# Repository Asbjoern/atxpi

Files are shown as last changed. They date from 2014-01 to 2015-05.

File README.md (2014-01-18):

# atxpi #

Raspberry Pi ATX power controller using the [teensy](http://www.pjrc.com/teensy/) microcontroller. The atxpi emulates ACPI behavior, handling ATX power supply states, power / reset buttons, and LEDs.

---

 - [Parts List](#parts-list)
 - [Power / Reset Buttons](#buttons)
 - [GPIO Pins](#gpio)
 - [RPI Power Scripts Installation](#power-scripts)
	- [Arch](#power-scripts-arch)
	- [Raspbian](#power-scripts-raspbian)
 - [Schematic](#schematic)

---

<h2 id="parts-list">Parts List</h2>

 - [Teensy 2.0](http://www.pjrc.com/store/teensy.html)
 - [Logic Level Converter](https://www.sparkfun.com/products/11978)
 - [ATX Connector Breakout Board](https://www.sparkfun.com/products/9558)
 - [ATX Power Supply Connector](https://www.sparkfun.com/products/9498)

---

<h2 id="buttons">Power / Reset Buttons</h2>

 - Power state 0:
	- Power button pressed: power on
	- Reset button pressed: do nothing

 - Power state 1:
	- Power button pressed for 1 second: Tell RPI to shutdown by setting GPIO pin 23 HIGH
	- Power button pressed for 5 seconds: Force power off
	- Reset button pressed for 1 second: Force power cycle

---

<h2 id="gpio">GPIO Pins</h2>

The RPI will monitor GPIO 23 and shutdown if it is set to HIGH. After the RPI boots it will set GPIO 24 HIGH, telling the teensy that the RPI is up. When GPIO 24 goes from HIGH to LOW the teensy will wait 5 seconds then cut power, unless GPIO 25 is HIGH. GPIO 25 is set to HIGH when the RPI is rebooting, preventing the teensy from cutting power when GPIO 24 changes from HIGH to LOW.

---

<h2 id="power-scripts">RPI Power Scripts Installation</h2>

<h3 id="power-scripts-arch">Arch</h3>

Log into the RPI and become root. You will need to install git and WiringPi:

	[root@alarmpi ~]$ pacman -Sy git wiringpi

Next, clone the repo and copy required files.

	[root@alarmpi ~]$ git clone https://github.com/steelcaverobotics/atxpi.git
	[root@alarmpi ~]$ mkdir /opt/atxpi
	[root@alarmpi ~]$ cp atxpi/rpi_power_scripts/*.sh /opt/atxpi/
	[root@alarmpi ~]$ chmod 755 /opt/atxpi/*.sh
	[root@alarmpi ~]$ cp atxpi/service_files/arch/*.service /usr/lib/systemd/system/

Then enable the services, skipping `atxpi-gpio-shutdown.service` if you don't want the RPI to shutdown when the power button is pressed.

	[root@alarmpi ~]$ systemctl enable atxpi-gpio-boot.service
	[root@alarmpi ~]$ systemctl enable atxpi-gpio-reboot.service
	[root@alarmpi ~]$ systemctl enable atxpi-gpio-shutdown.service

Finally, start the services. Do not start `atxpi-gpio-reboot.service`, as this will be started when the RPI is rebooting.

	[root@alarmpi ~]$ systemctl start atxpi-gpio-boot.service
	[root@alarmpi ~]$ systemctl start atxpi-gpio-shutdown.service

<h3 id="power-scripts-raspbian">Raspbian</h3>

Log into the RPI and become root. You will need to install git and WiringPi:

	root@raspberrypi:~# apt-get install git-core
	root@raspberrypi:~# git clone git://git.drogon.net/wiringPi
	root@raspberrypi:~# cd wiringPi/
	root@raspberrypi:~# ./build

Next, clone the repo and copy required files.

	root@raspberrypi:~# git clone https://github.com/steelcaverobotics/atxpi.git
	root@raspberrypi:~# mkdir /opt/atxpi
	root@raspberrypi:~# cp atxpi/rpi_power_scripts/*.sh /opt/atxpi/
	root@raspberrypi:~# chmod 755 /opt/atxpi/*.sh
	root@raspberrypi:~# cp atxpi/service_files/raspbian/* /etc/init.d/
	root@raspberrypi:~# chmod 755 /etc/init.d/atxpi-gpio-*

Then enable the services, skipping `atxpi-gpio-shutdown` if you don't want the RPI to shutdown when the power button is pressed.

	root@raspberrypi:~# update-rc.d atxpi-gpio-boot defaults
	root@raspberrypi:~# update-rc.d atxpi-gpio-reboot defaults
	root@raspberrypi:~# update-rc.d atxpi-gpio-shutdown defaults

Finally, start the services.

	root@raspberrypi:~# /etc/init.d/atxpi-gpio-boot start
	root@raspberrypi:~# /etc/init.d/atxpi-gpio-shutdown start

---

<h2 id="schematic">Schematic</h2>

<a href="https://dl.dropboxusercontent.com/u/7536257/atxpi/atxpi_schematic_large.png" target="_blank">
	atxpi schematic
</a>

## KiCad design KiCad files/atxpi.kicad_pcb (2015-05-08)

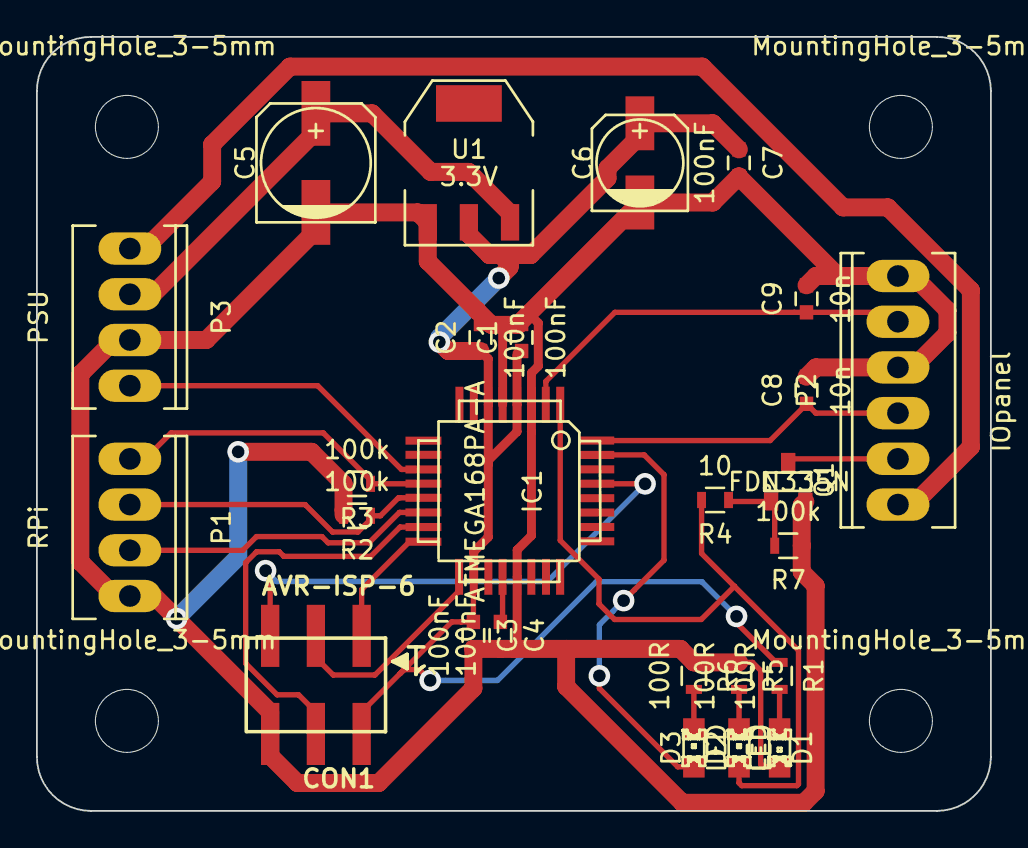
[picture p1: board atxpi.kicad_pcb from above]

Board: 2 copper layers, 53.0 x 43.0 mm, 30 parts (0 on the bottom side), 22 nets.

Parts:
C1, C2, C3, C4, C7: 100nF; C_0603
C5: >100uF; c_elec_6.3x5.8
C6: 10uF; c_elec_5x5.3
C8, C9: 10n; C_0603
CON1: AVR-ISP-6; pin_2x6_smd
D1, D2, D3: LED; LED-0805
IC1: ATMEGA168PA-A; TQFP-32
MountingHole_3-5mm, MountingHole_3-5mm#2, MountingHole_3-5mm#3, MountingHole_3-5mm#4: VAL**; MountingHole_3-5mm
P1: RPi; Socket_MOLEX-KK-RM2-54mm_Lock_4pin_straight
P2: IOpanel; Socket_MOLEX-KK-RM2-54mm_Lock_6pin_straight
P3: PSU; Socket_MOLEX-KK-RM2-54mm_Lock_4pin_straight
Q1: FDN335N; SOT-23
R1, R5, R6: 100R; R_0603
R2, R3, R7: 100k; R_0603
R4: 10; R_0603
U1: 3.3V; SOT-223

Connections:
+3.3V: C1.1, C2.1, C3.1, C6.1, C7.1, CON1.2, IC1.4, IC1.6, IC1.18, R1.1, U1.2
+5V: C5.1, P3.2, U1.3
+12V: P2.1, P3.1
/MISO: CON1.1, IC1.16
/MOSI: CON1.4, IC1.15
/PS_ON: IC1.11, P3.4
/PWR_LED: D2.1, IC1.1, R4.2
/PWR_SW: C8.1, IC1.32, P2.3
/RDY_LED: D3.1, IC1.31
/RPI_REBOOT_25: IC1.12, P1.1, R3.1
/RPI_UP_24: IC1.13, P1.2, R2.1
/RST: CON1.5, IC1.29
/RST_SW: C9.1, IC1.2, P2.5
/SCK: CON1.3, IC1.17
/SHTDWN_23: IC1.14, P1.3
GND: C1.2, C2.2, C3.2, C4.2, C5.2, C6.2, C7.2, C8.2, C9.2, CON1.6, D1.2, IC1.3, IC1.5, IC1.21, P1.4, P2.4, P2.6, P3.3, Q1.2, R2.2, R3.2, R5.1, R6.1, R7.1, U1.1
unnamed: C4.1, IC1.20
unnamed: D1.1, R1.2
unnamed: D2.2, R5.2
unnamed: D3.2, R6.2
unnamed: P2.2, Q1.3
unnamed: Q1.1, R4.1, R7.2

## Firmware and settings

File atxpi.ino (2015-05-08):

#define DEBUG 0

#include <Bounce2.h>
#include <elapsedMillis.h>

#define READY_LED 1
#define POWER_LED 3
#define POWER_SWITCH 2
#define RESET_SWITCH 4
#define PI_GPIO_23 10 // used to tell rpi to shutdown
#define PI_GPIO_24 9 // used to tell teensy the rpi is up, and when to cut power
#define PI_GPIO_25 8 // used to tell the teensy the rpi is rebooting (don't cut power)
#define PS_ON 7


int power_state = 0;
int soft_shutdown_triggered = 0;
int rpi_is_up = 0;
int rpi_rebooting = 0;
Bounce power_button = Bounce();
Bounce reset_button = Bounce();
elapsedMillis power_button_timer;
elapsedMillis reset_button_timer;


void powerOn() {
  digitalWrite(PS_ON, LOW);
  digitalWrite(POWER_LED, HIGH);
  power_state = 1;
  delay(1000); // allow rpi gpio lines to stabilize
}


void powerOff() {
  digitalWrite(PS_ON, HIGH);
  digitalWrite(POWER_LED, LOW);
  digitalWrite(PI_GPIO_23, LOW);
  power_state = 0;
  rpi_is_up = 0;
}


void setup() {
#if DEBUG
  Serial.begin(115200);
#endif
  pinMode(READY_LED, OUTPUT);
  pinMode(POWER_LED, OUTPUT);
  pinMode(PI_GPIO_23, OUTPUT);
  pinMode(PS_ON, OUTPUT);
  pinMode(PI_GPIO_23, OUTPUT);

  pinMode(PI_GPIO_24, INPUT);
  pinMode(PI_GPIO_25, INPUT);
  pinMode(POWER_SWITCH, INPUT_PULLUP);
  pinMode(RESET_SWITCH, INPUT_PULLUP);
  power_button.attach(POWER_SWITCH);
  reset_button.attach(RESET_SWITCH);
  power_button.interval(5);
  reset_button.interval(5);

  powerOff();

  digitalWrite(READY_LED, HIGH);
#if DEBUG
  Serial.println("atxpi online");
#endif
}


void loop() {
  power_button.update();
  if(power_button.fell()) {
#if DEBUG
    Serial.println("power button pressed");
#endif
    if(power_state == 0) { // activate psu
#if DEBUG
      Serial.println("power_state: 0, activating psu");
#endif
      powerOn();
    }
    else { // deactivate psu via power button
#if DEBUG
      Serial.println("power_state: 1, shutdown");
#endif
      power_button_timer = 0;
      for(; !power_button.rose(); power_button.update()) {
        if(!soft_shutdown_triggered && power_button_timer >= 1000) {
          // power button held down for 1 second, tell rpi to shutdown
          soft_shutdown_triggered = 1; // set this so the soft shutdown will only be triggered once per power button press
          digitalWrite(PI_GPIO_23, HIGH);
#if DEBUG
          Serial.println("soft shutdown triggered");
#endif
        }
        if(power_button_timer >= 5000) {
#if DEBUG
          Serial.println("forcing shutdown");
#endif
          // power button held down for 5 seconds, force shutdown
          powerOff();
          break;
        }
      }
      soft_shutdown_triggered = 0;
    }
  }

  reset_button.update();
  if(power_state == 1 && reset_button.fell()) {
#if DEBUG
    Serial.println("reset button pressed");
#endif
    reset_button_timer = 0;
    for(; !reset_button.rose(); reset_button.update()) {
      if(reset_button_timer >= 1000) {
        // reset button held down for 1 second, cycle power
#if DEBUG
        Serial.println("cycling power");
#endif
        powerOff();
        delay(2000);
        powerOn();
        break;
      }
    }
  }

  // set rpi_is_up to 1 when PI_GPIO_24 goes high
  if(power_state && !rpi_is_up && digitalRead(PI_GPIO_24)) {
#if DEBUG
    Serial.println("rpi_is_up = 1");
#endif
    rpi_is_up = 1;
  }

  // allow rpi to reboot without cutting power
  if(rpi_is_up && digitalRead(PI_GPIO_25)) {
#if DEBUG
    Serial.println("rpi rebooting, waiting for GPIO 25 to go LOW");
#endif
    rpi_is_up = 0; // stop power from being cut
    for(; digitalRead(PI_GPIO_25);) { // wait untill rpi has rebooted
    }
#if DEBUG
    Serial.println("GPIO 25 has gone LOW");
#endif
  }

  // cut power once rpi has shutdown
  if(rpi_is_up && !digitalRead(PI_GPIO_24)) {
#if DEBUG
    Serial.println("rpi has shutdown, cutting power");
#endif
    delay(5000);
    powerOff();
#if DEBUG
    Serial.println("power cut");
#endif
  }

#if DEBUG
  int incomming_byte = 0;
  if(Serial.available() > 0) {
    incomming_byte = Serial.read();
    switch(incomming_byte) {
    case 48: // '0': trigger soft shutdown
      digitalWrite(PI_GPIO_23, HIGH);
      Serial.println("debug: soft shutdown triggered");
      break;
    case 49: // '1': power on
      if(power_state == 0) {
        Serial.println("debug: power on");
        powerOn();
      }
      else {
        Serial.println("debug: power already on");
      }
      break;
    case 99: // 'c': clear soft shutdown GPIO line
      digitalWrite(PI_GPIO_23, LOW);
      Serial.println("debug: PI_GPIO_23 set to LOW");
      break;
    case 102: // 'f': force poweroff
      powerOff();
      Serial.println("debug: forced poweroff");
      break;
    case 114: // 'r': cycle power
      Serial.println("debug: cycling power");
      powerOff();
      delay(2000);
      powerOn();
      break;
    default:
      break;
    }
  }
#endif
}

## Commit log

2013-09-16 started atxpi code for the teensy2.0 microcontroller
2013-09-18 implemented power and reset button functionality
2013-09-27 turned off debug, added hdd led, and changed pin numbers
2013-09-28 changed forced shutdown and reset times
    [atxpi.ino]
2013-11-11 add atxpi eagle schematic
    [atxpi.sch]
2013-11-11 update and fix atxpi schematic
    [atxpi.sch]
2013-11-27 add rpi power scripts
2013-11-27 fix gpio pin number in reboot.sh
2014-02-11 add atxpi board
    [atxpi.brd, atxpi.sch]
2015-05-08 Replaced Teensy/Eagle hardware with ATMEGA328 PCB mounted design
    [atxpi.brd, atxpi.kicad_pcb, atxpi.sch]
2015-05-08 Swithed pins to new design and replaced Bounce with Bounce2 library
    [atxpi.ino]

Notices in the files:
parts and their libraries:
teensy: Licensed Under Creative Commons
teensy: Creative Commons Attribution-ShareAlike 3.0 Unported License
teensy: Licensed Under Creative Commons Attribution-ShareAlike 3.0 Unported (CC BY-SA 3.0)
